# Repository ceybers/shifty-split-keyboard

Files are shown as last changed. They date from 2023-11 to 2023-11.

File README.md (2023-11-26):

# Shifty Split Keyboard

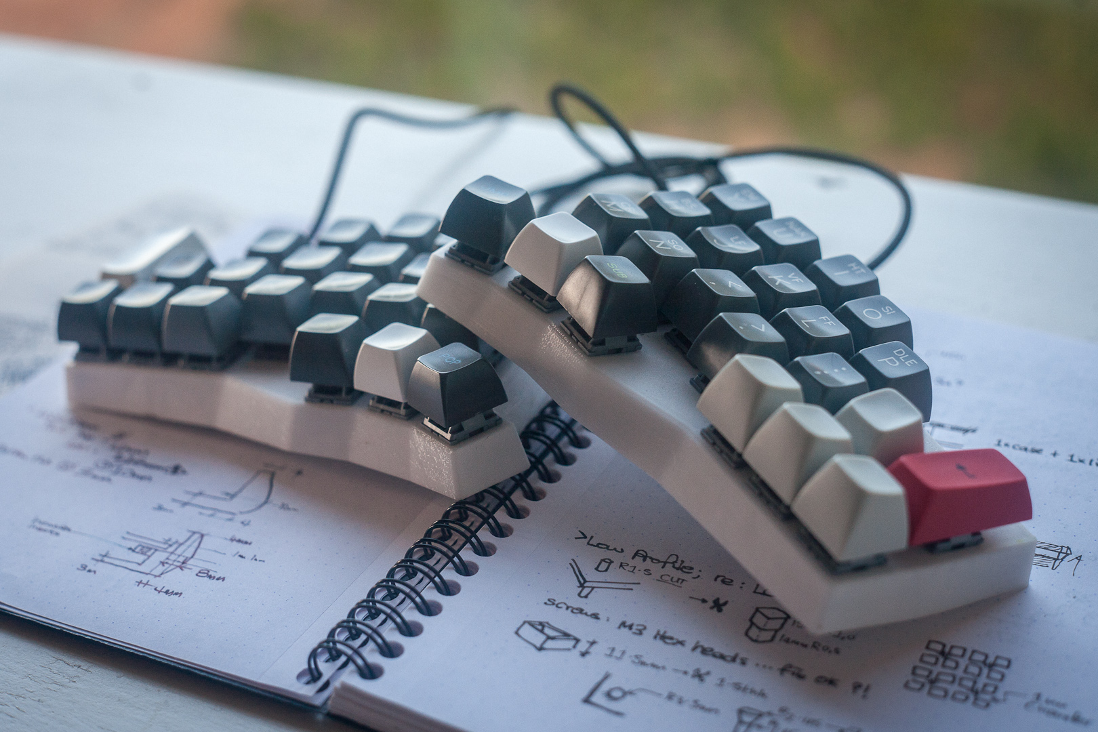
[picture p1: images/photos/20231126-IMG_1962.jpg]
Photo of my Shifty Split keyboard


## 📻 Project Description

Yet another 44-key handwired split keyboard. 

I liked the [Void Ergo S](https://github.com/victorlucachi/void_ergo), but I want to try a Corne style keyboard with a (semi-)dedicated arrow cluster, like the [Frame-48](https://github.com/gregsqueeb/Frame-48). I also added a vertical 2u key on each end where the numpad Enter key would be on a full-size keyboard, because of muscle memory, partially inspired by the [Skean's](https://github.com/krikun98/Skean) outer keys.

[Continue reading...](notes/Design.md)

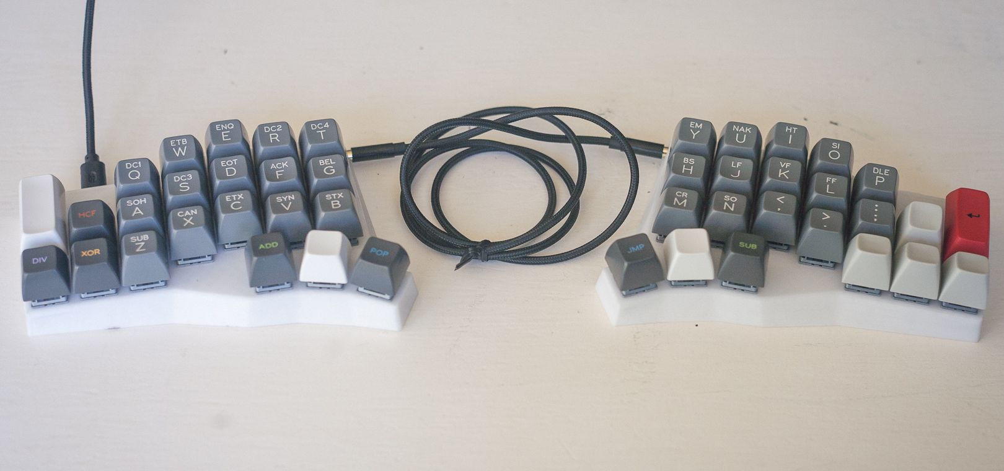
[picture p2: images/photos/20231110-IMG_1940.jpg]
Photo of my Shifty Split keyboard


## 🧰 Features
- 22×2 keys
- 2× RP2040 microcontrollers w/ USB-C on each side
- Split via TRS cable
- Powered by QMK with Vial support

## 📚 Read more...
- [Design](notes/Design.md)
- [Construction](notes/Construction.md)
- [Firmware](notes/Firmware.md)
- [Gallery](notes/Gallery.md)

## 🙏 Inspired by...
- [VOID Ergo S by Victor Lucachi](https://github.com/victorlucachi/void_ergo)
- [Frame-48 by Greg Mathews](https://github.com/gregsqueeb/Frame-48)
- [Skean by Alexander Krikun](https://github.com/krikun98/Skean)
- [MicroDox by Stephen Onnenon](https://github.com/onnenon/microdox-case/)
- [Unicorne by Boardsource](https://new.boardsource.xyz/products/unicorne)

## 📐 References
- [RP2040-Zero by Waveshare](https://www.waveshare.com/rp2040-zero.htm)
- [QMK Firmware](https://docs.qmk.fm/)
- [Vial Firmware](https://get.vial.today/)

---

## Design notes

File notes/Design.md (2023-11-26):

# Design
Yet another 44-key handwired split keyboard. 

I liked the [Void Ergo S](https://github.com/victorlucachi/void_ergo), but I want to try a Corne style keyboard with a (semi-)dedicated arrow cluster, like the [Frame-48](https://github.com/gregsqueeb/Frame-48). I also added a vertical 2u key on each end where the numpad Enter key would be on a full-size keyboard, because of muscle memory, partially inspired by the [Skean's](https://github.com/krikun98/Skean) outer keys.

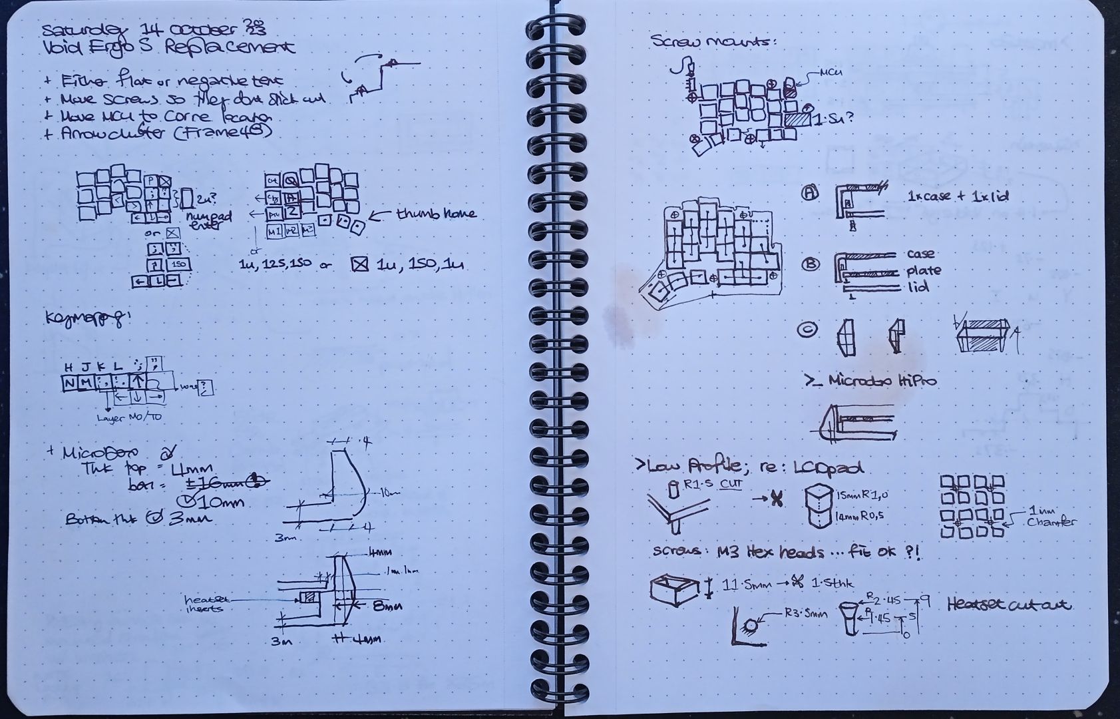
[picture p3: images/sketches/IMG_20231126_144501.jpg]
Sketch experimenting with arrow cluster


The arrow clusters line up nicely with the 5th and 6th column from the Void Ergo (same Y offset), and this conveniently leaves an empty key where the top row 6th column key would normally be, which is just enough space to fit a small RP2040 MCU. 

For the outer easy key, I chose a vertical 2u key because of years of muscle memory hitting the number pad Enter key. I was considering placing it horizontally, but I wasn't happy with the resulting silhouette of the keyboard, so I stuck to the current layout.

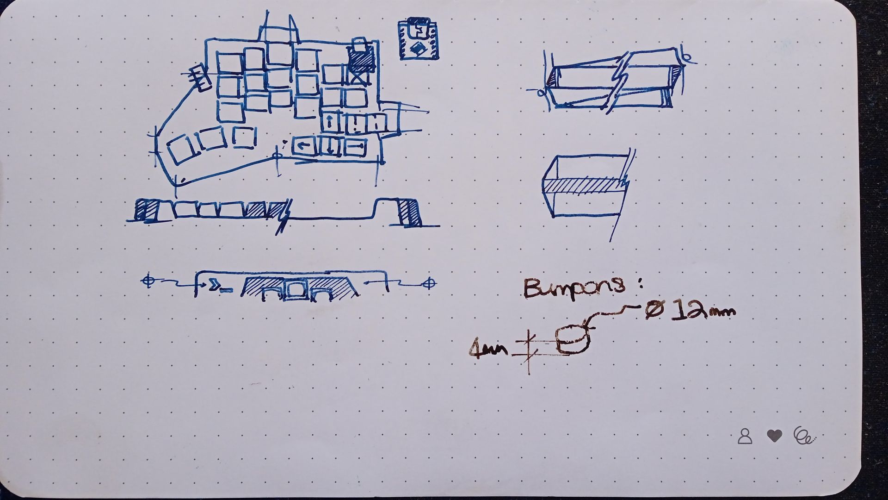
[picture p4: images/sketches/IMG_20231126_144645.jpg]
Sketch with horizontal outer key


It's 3D printed and handwired. The plate and the case are one part to avoid having to hassle with heatsets and screws. The bottom plate is recessed inside the walls of the top case, to hide imperfections with clearance and tolerance between the two parts. Then, I added a generous amount of slope and loft to the walls of the case to break up the silhouette because that appeals my personal taste.

As for the name? I needed something to put where the empty key was, so I decided to add a `>_>` face.

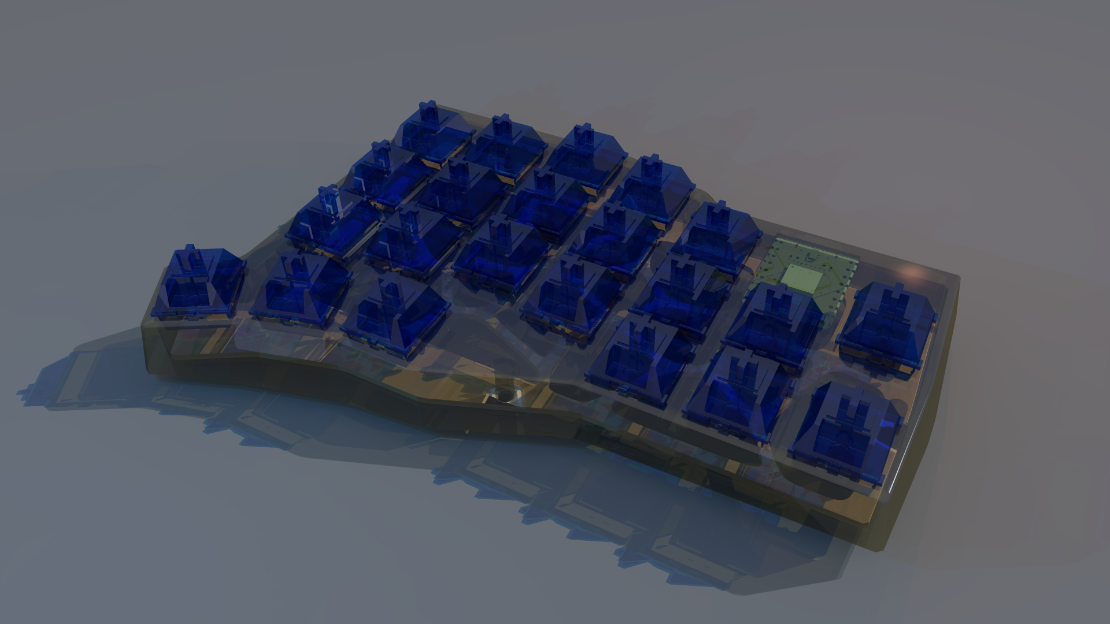
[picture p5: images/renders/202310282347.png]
Render of the Shifty Split keyboard


---

Next: [Construction](Construction.md) | Back to [README.md](../README.md)

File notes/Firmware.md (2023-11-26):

# Firmware
## QMK and Vial
For the firmware I first used the official [QMK](https://docs.qmk.fm/) repo to ensure everything is working and wired up correctly. Once I had the QMK firmware working and flashed to the board, I installed the [Vial](https://get.vial.today/) fork of QMK, and created a Vial-compatible firmware using their instructions.

I managed to get the WS2812 LED on the RP2040-Zero sort of working, but I could only change it inside the Vial interface and not using the actual keys, so I disabled it. Plus the LED faces down so the glow is rather faint. 

Still, it's useful while experimenting to indicate whether the keyboard has been flashed correctly.

## Keymaps
My keymaps were heavily inspired by manna-harbour's [Miryoku](https://github.com/manna-harbour/miryoku) layout, as well as learnings from Precondition's [Guide to Home Row Mods](https://precondition.github.io/home-row-mods).

### Layer 0
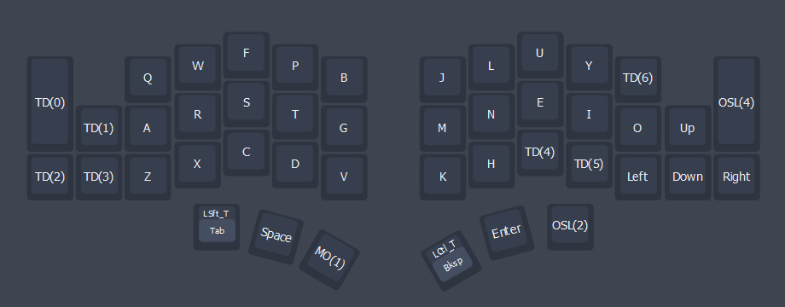
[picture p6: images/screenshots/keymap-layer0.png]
Keymap Layer 0

### Layer 1
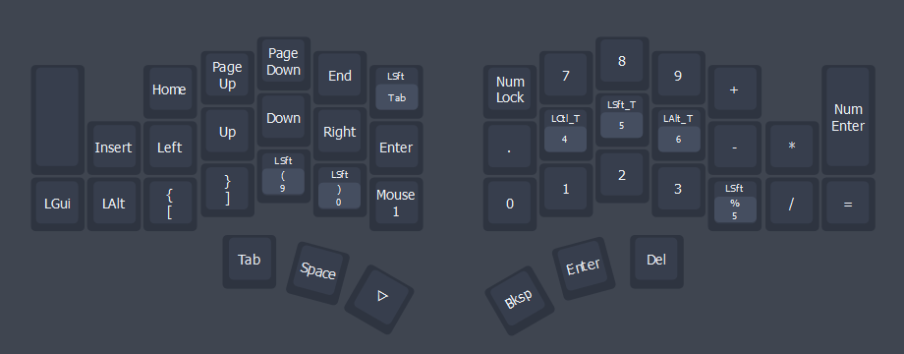
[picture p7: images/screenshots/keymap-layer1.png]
Keymap Layer 1

### Layer 2
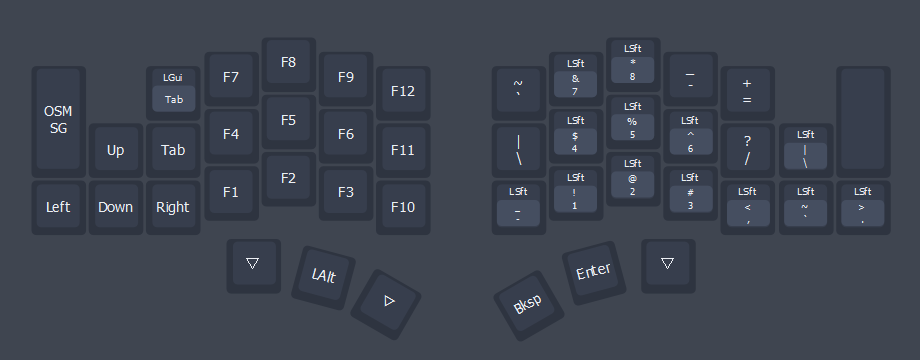
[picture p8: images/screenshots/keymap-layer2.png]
Keymap Layer 2

### Layer 4
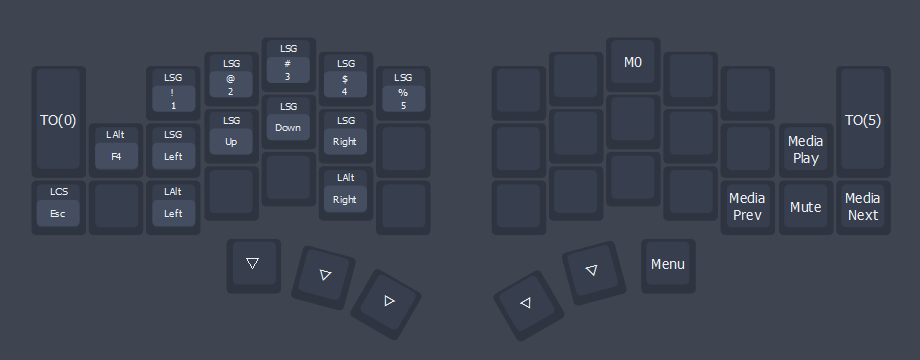
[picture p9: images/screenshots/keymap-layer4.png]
Keymap Layer 4

### Layer 5
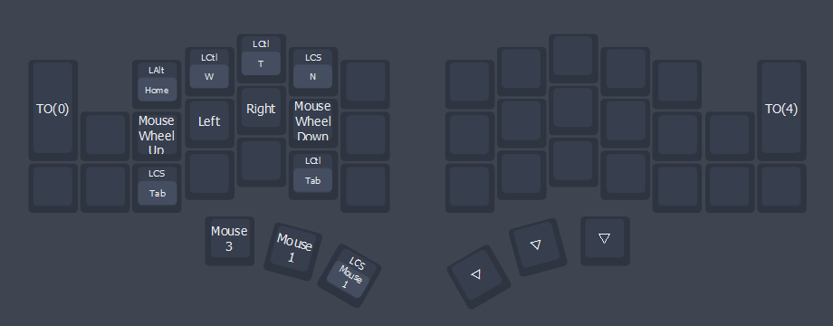
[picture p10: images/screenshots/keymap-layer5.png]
Keymap Layer 5


The tap dances on the left half are mostly hotkeys such as Ctrl-C, Ctrl-X, Ctrl-V, Ctrl-A, and Ctrl-C. I have tap dances for the command and period keys because I like having question mark, exclamation mark, single quote and quotation marks there.

I'm happy with my numpad layout and the navigation, but I'm not too sold on the brackets. Layer 2's symbols on the numpad are okay, but the ones around it don't feel very intuitive.

Layer 4 is handy because I have media keys by hitting the 2u key once (one-shot) then one of the arrow keys.

Hitting the 2u RHS key twice takes you to a browser layer, where the usual browser hotkeys are all a single tap, with mouse buttons available for making using a trackball with the right hand a bit easier.

## Some extra sketches
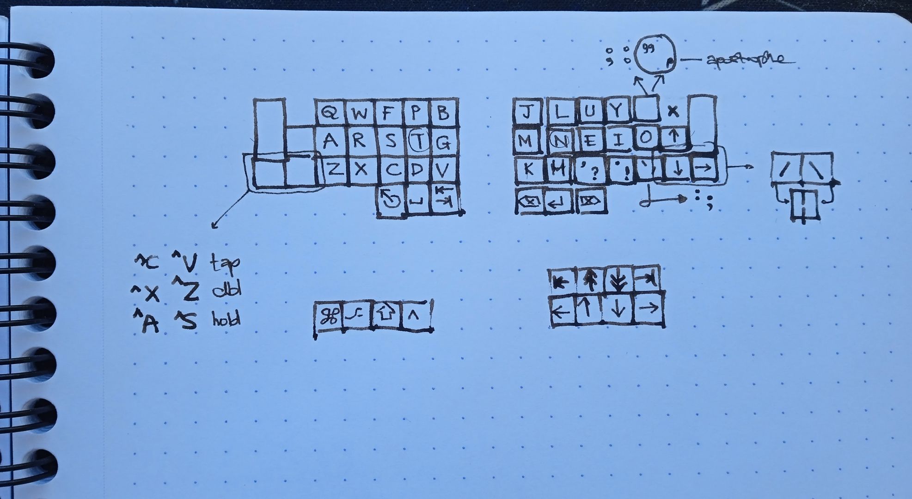
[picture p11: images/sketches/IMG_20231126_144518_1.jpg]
Sketch of preliminary base layer

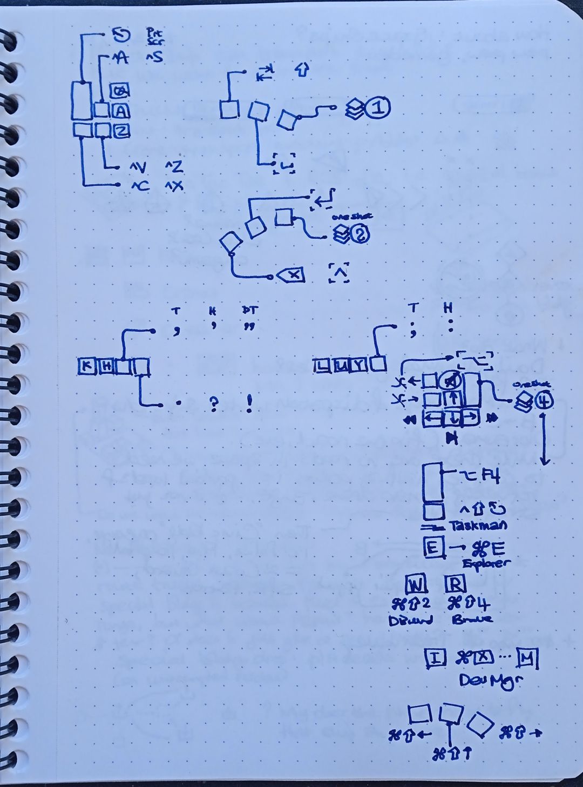
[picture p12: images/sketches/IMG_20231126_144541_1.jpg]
Sketches of some tapdance ideas

---

Back: [Construction](Construction.md) | Next: [Gallery](Gallery.md) | Back to [README.md](../README.md)

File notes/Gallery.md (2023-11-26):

# Gallery
## Photos
Artsy photo
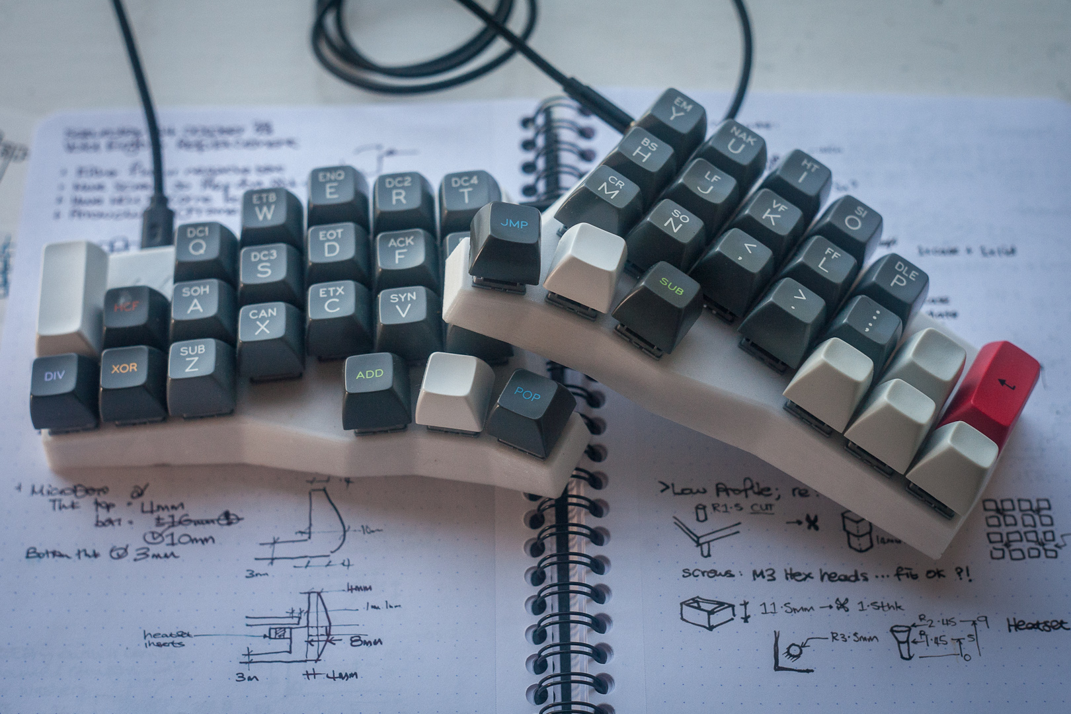
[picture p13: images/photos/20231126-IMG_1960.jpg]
Top down view

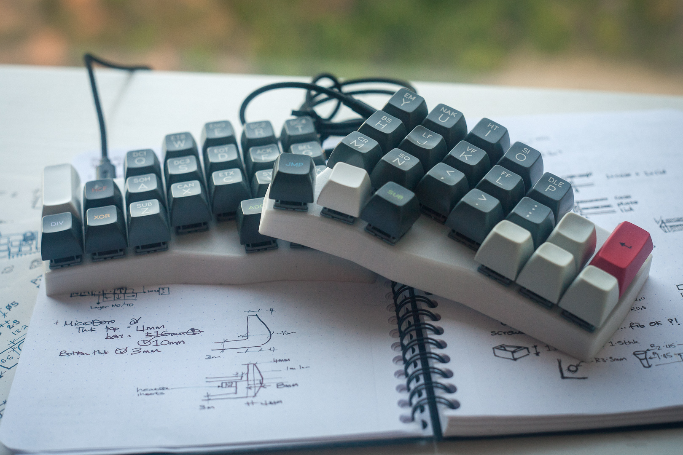
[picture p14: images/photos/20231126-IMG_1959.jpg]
Front angle view

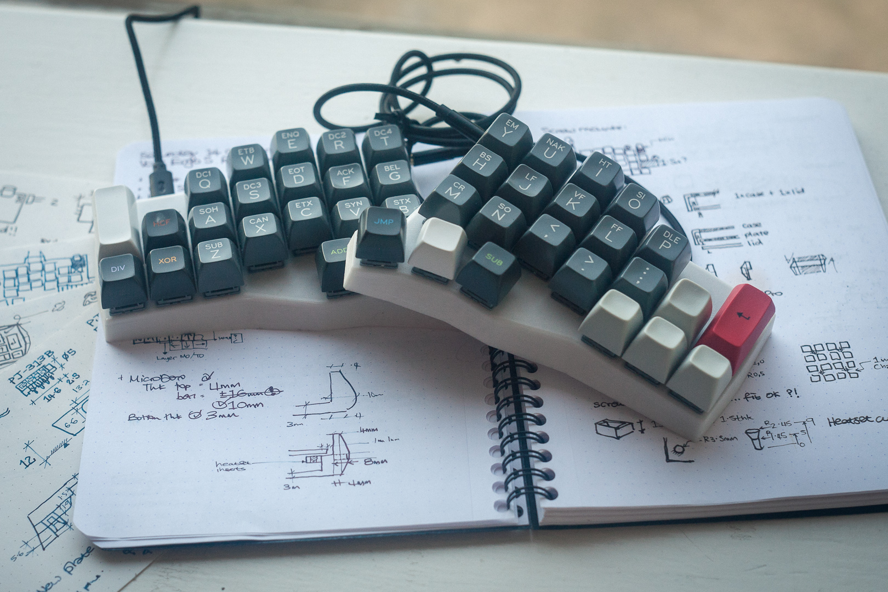
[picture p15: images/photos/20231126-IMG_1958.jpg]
Another top down view

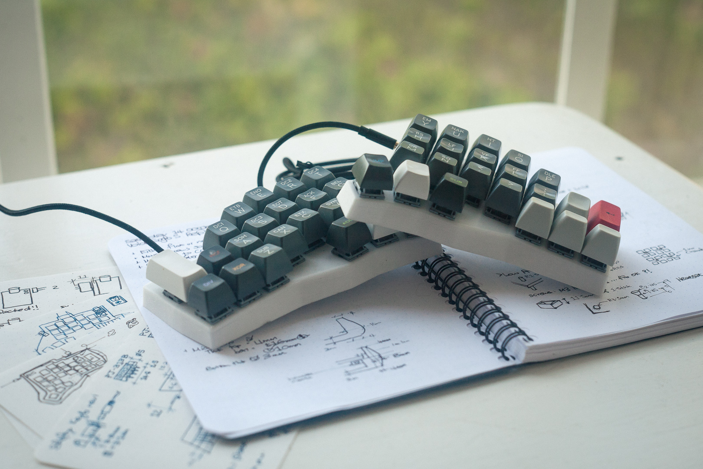
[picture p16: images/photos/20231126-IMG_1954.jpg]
Artsy angle view

Both halves
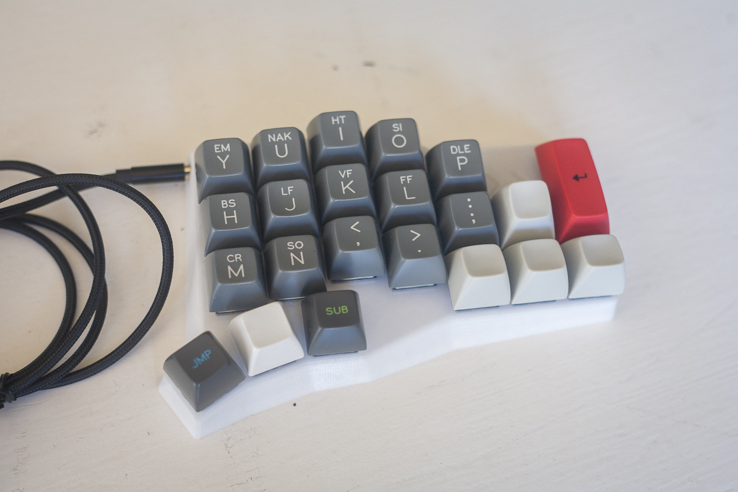
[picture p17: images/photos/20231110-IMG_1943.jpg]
Left half

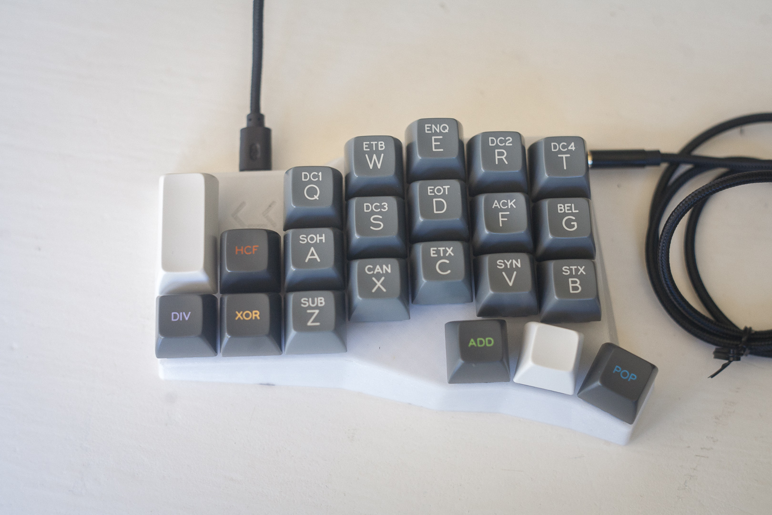
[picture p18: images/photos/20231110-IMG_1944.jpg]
Right half

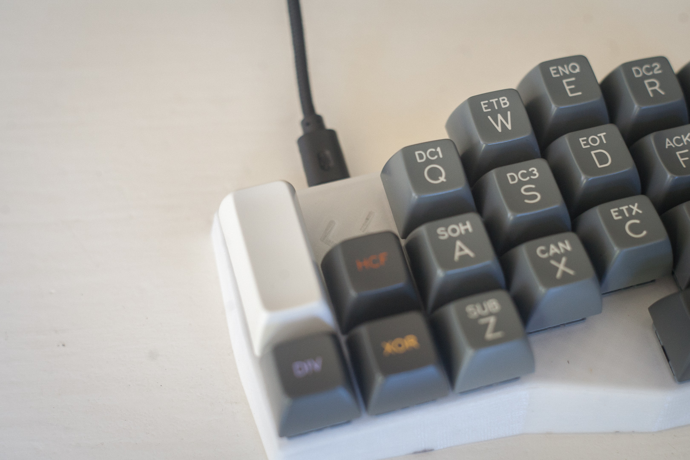
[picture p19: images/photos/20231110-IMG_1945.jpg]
Right half closeup

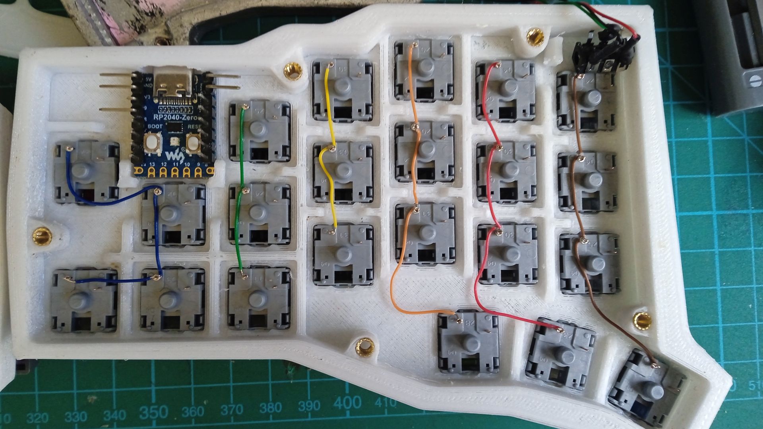
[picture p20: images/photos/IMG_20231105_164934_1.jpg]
Underside wiring


## Renders
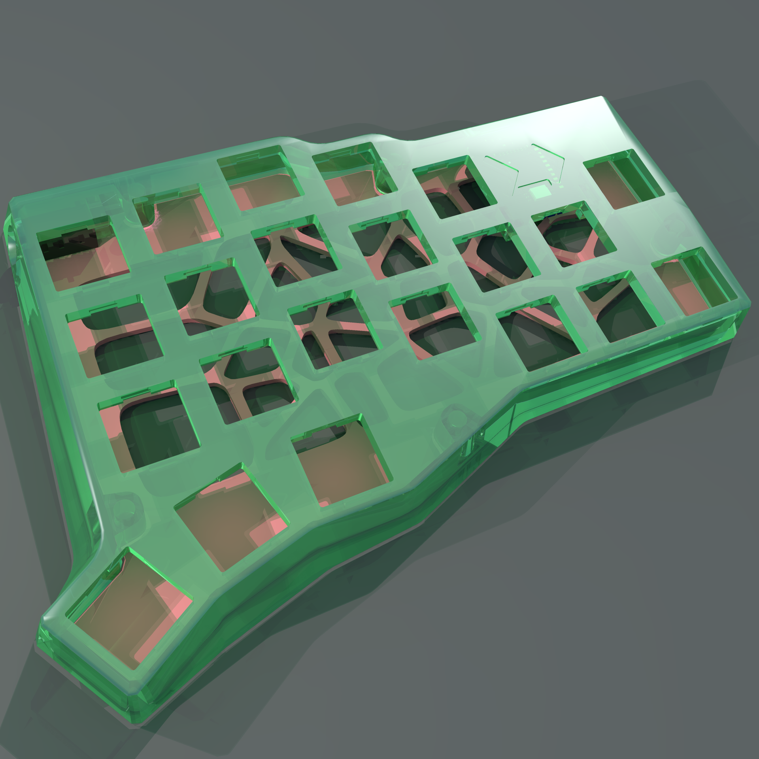
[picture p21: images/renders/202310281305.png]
Render w/o keys

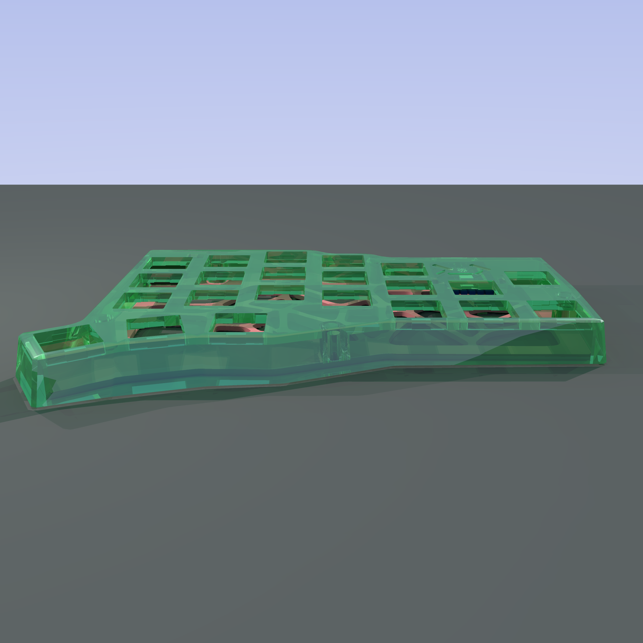
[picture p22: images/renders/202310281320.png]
Render w/o keys

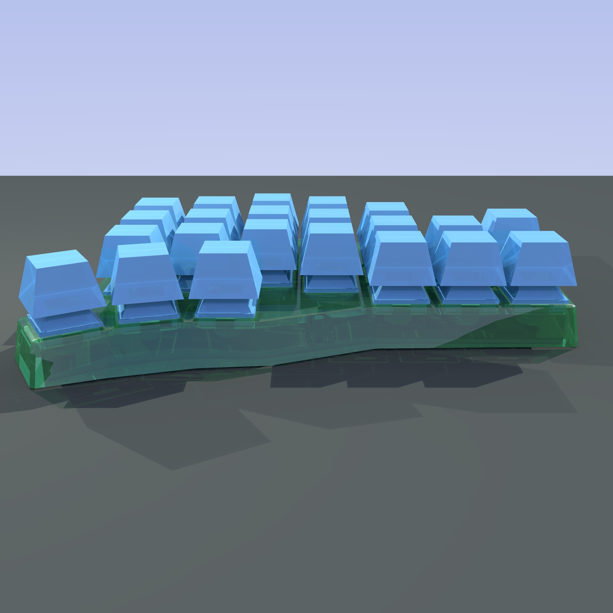
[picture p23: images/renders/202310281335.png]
Render w/ keys

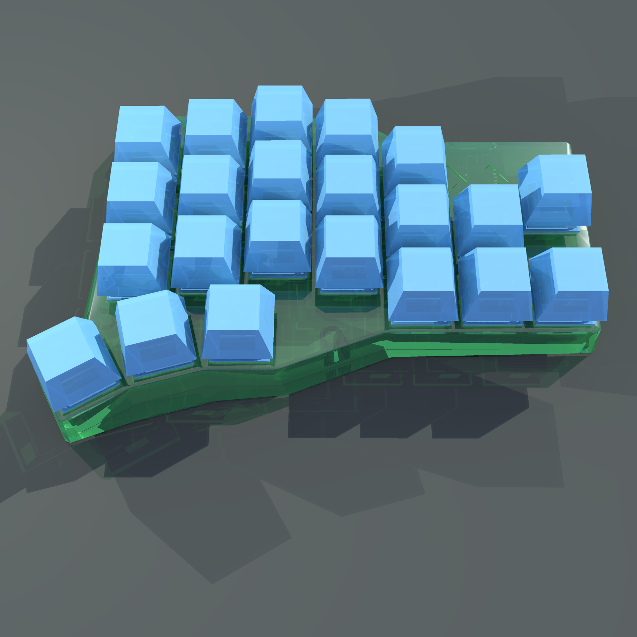
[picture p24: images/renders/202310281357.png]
Render w/ keys

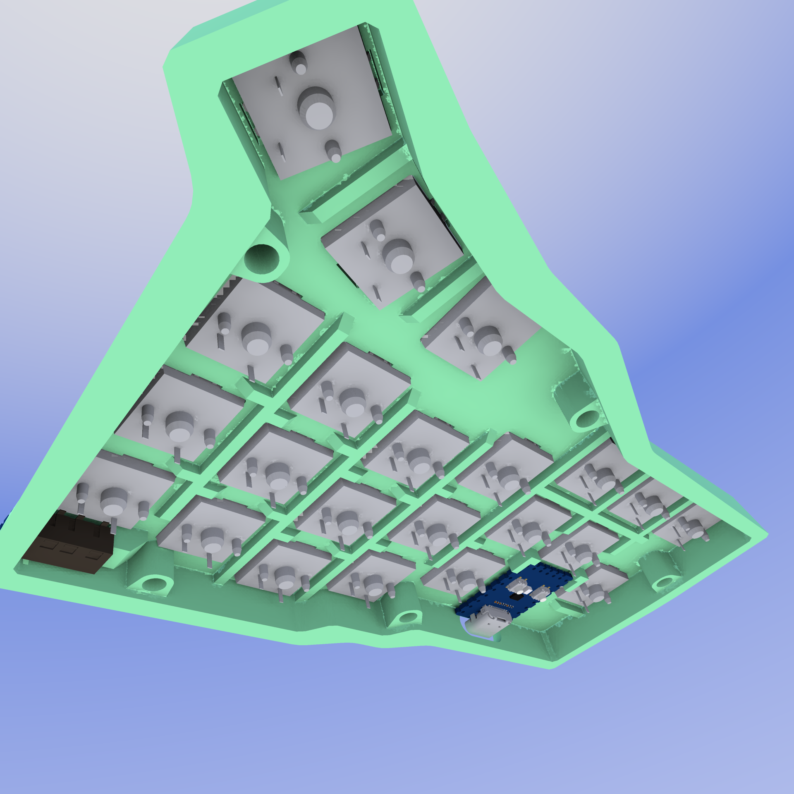
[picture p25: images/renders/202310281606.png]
Render underside

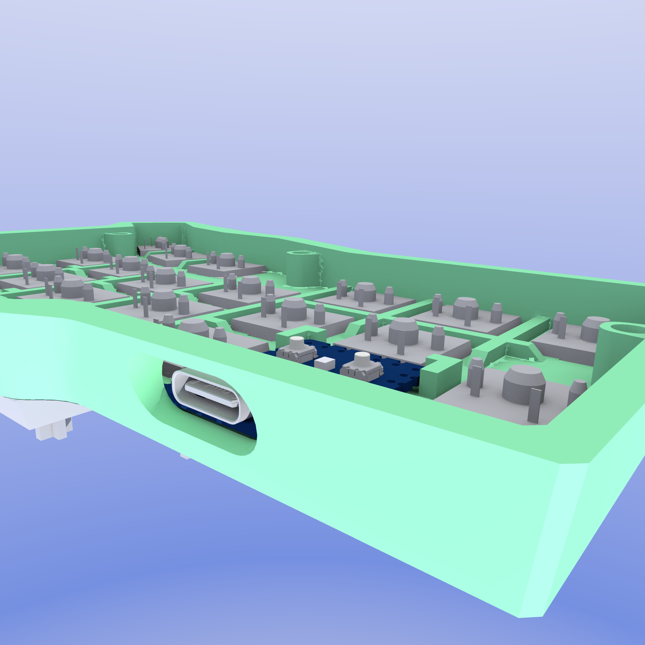
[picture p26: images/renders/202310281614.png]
Render underside USB-C

Upside down with bottom cover
Top transparent render

---

Back: [Firmware](Firmware.md) | Back to [README.md](../README.md)

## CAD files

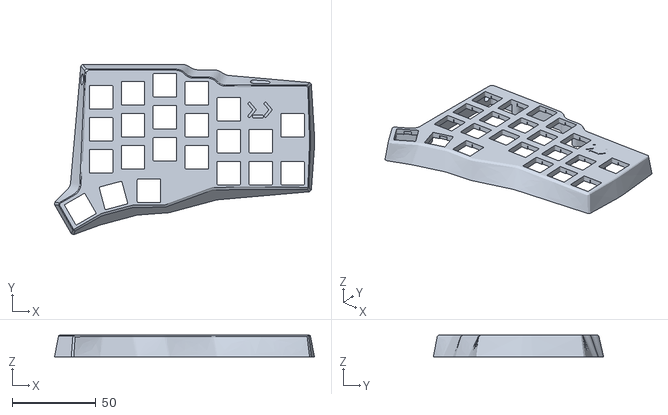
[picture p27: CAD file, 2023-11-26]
export/keyb-case-right-rev1.stl
155.1 x 101.6 x 13.0

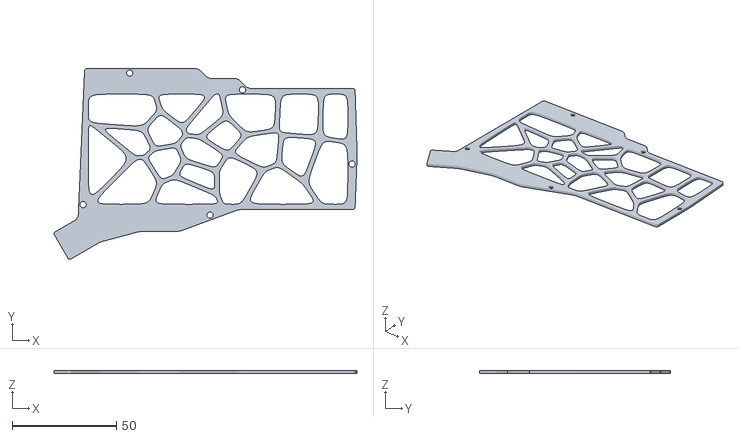
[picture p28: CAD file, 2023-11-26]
export/keyb-bottom-right-rev0.stl
145.1 x 91.3 x 1.50

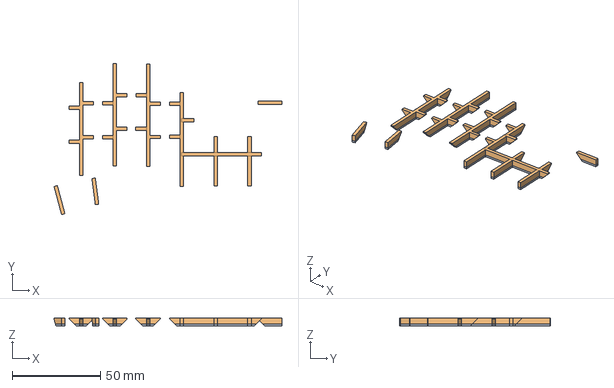
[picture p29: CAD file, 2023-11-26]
freecad/CaseRibbing.FCStd
129.1 x 85.6 x 4.50 mm
CaseRibNice

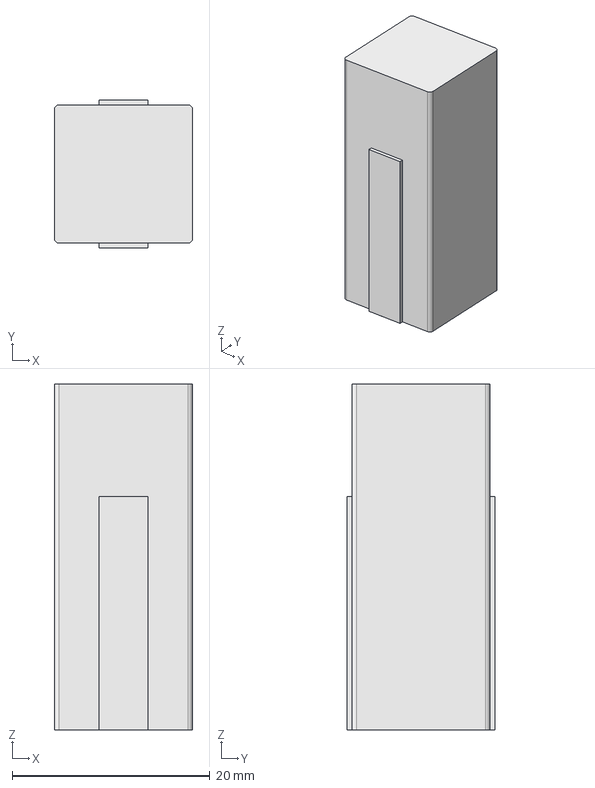
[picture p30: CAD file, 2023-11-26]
freecad/MXCutout.FCStd
14.0 x 15.0 x 35.0 mm

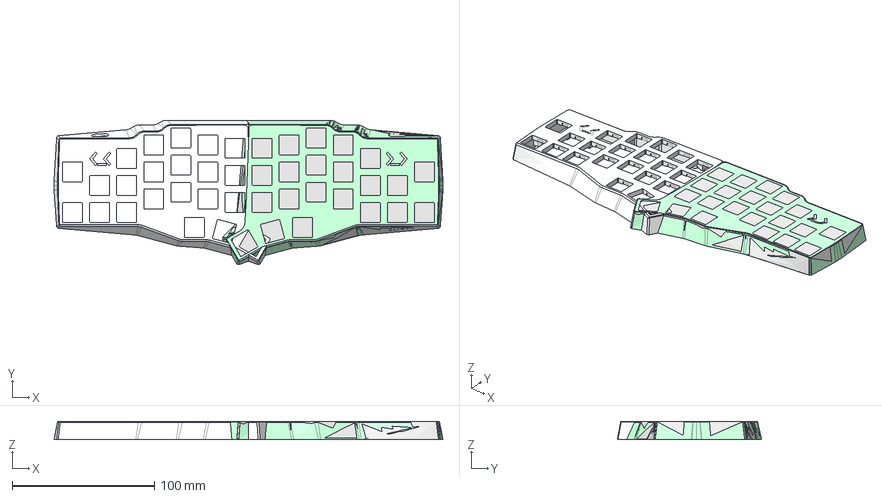
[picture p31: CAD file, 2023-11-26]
freecad/plate6.FCStd
273.7 x 101.6 x 13.0 mm
CaseSolid
CaseNice
CaseNice (Mirror #1)

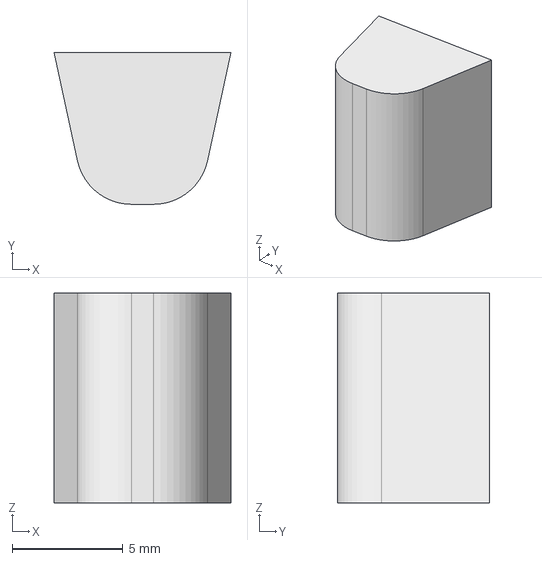
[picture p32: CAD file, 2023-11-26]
freecad/HeatSetInsertHolder.FCStd
8.00 x 6.86 x 9.50 mm

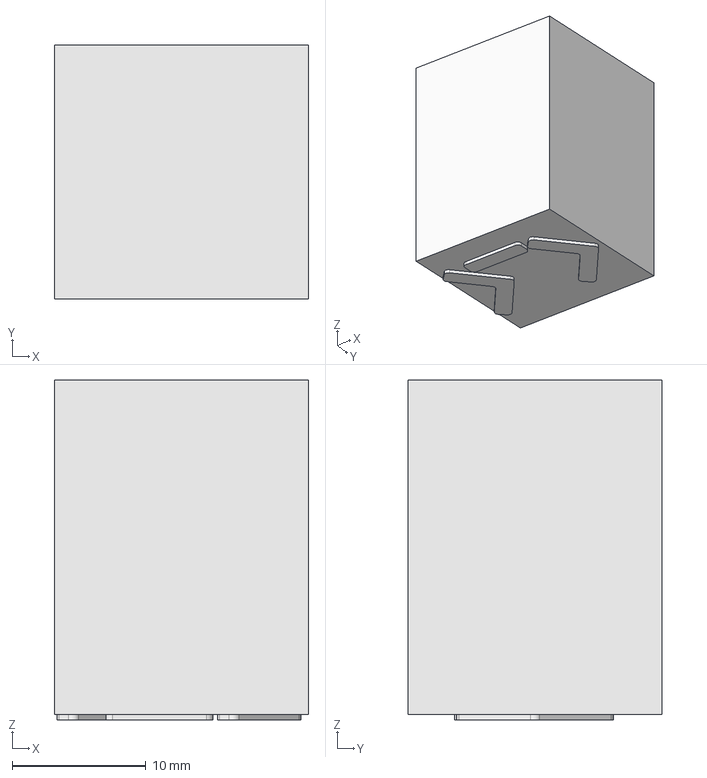
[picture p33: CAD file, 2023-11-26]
freecad/Shifty.FCStd
19.0 x 19.0 x 25.4 mm

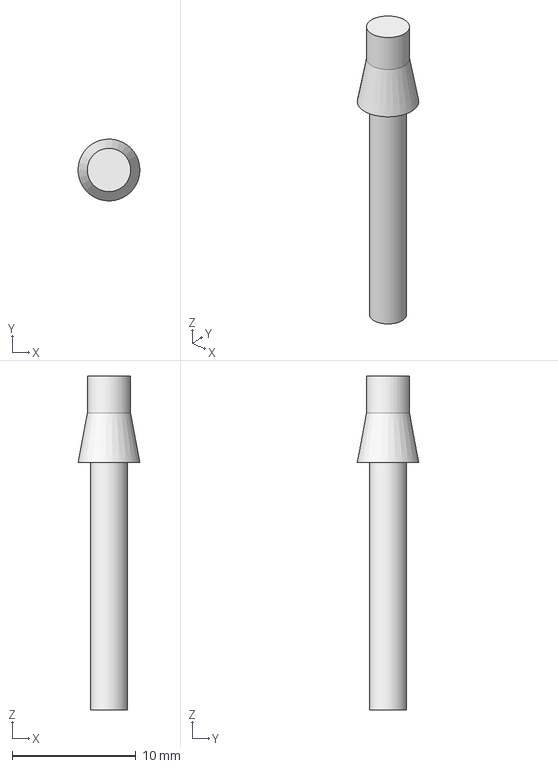
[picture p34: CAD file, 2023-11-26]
freecad/ScrewAndInsertCutout.FCStd
5.00 x 5.00 x 27.0 mm

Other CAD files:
export/keyb-case-left-rev1.stl
freecad/CombinedScene.FCStd
export/keyb-bottom-left-rev0.stl

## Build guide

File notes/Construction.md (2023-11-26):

# Construction

## 🛒 Bill of Materials (BOM)

| Item | Size | Qty | 
| ---- | ---- | --- |
| [Waveshare RP2040-Zero](https://www.waveshare.com/rp2040-zero.htm) | N/A | 2 |
| Switches | MX | 44 |
| Diodes, 1N4148 | 1N4148 | 44 |
| PJ320D 3.5mm Female | TRS† | 2|
| Heat Set Inserts | M3 ø4x5mm | 10 |
| Screws, countersunk | M3 | 10 |
| Wire | 30AWG | N/A |
| 3D printed shell | N/A | 4 pcs |

† Test the cable(s) you intend using, as TRS and TRRS connectors are not always compatible.

## 📸 Photos
I didn't take many photos during the build of this one. The biggest challenge is the tight spacing around the MCU, as can be seen below:

Photo from beneath showing column wiring

Note the 90 degree header pins next to the USB-C port. These are for 3v3, GND, and a serial pin for the split cable between the halves. For this I decided to use a battery header pins because they're sturdier than the usual 30AWG wire I use that *does* tend to come loose on occasion.

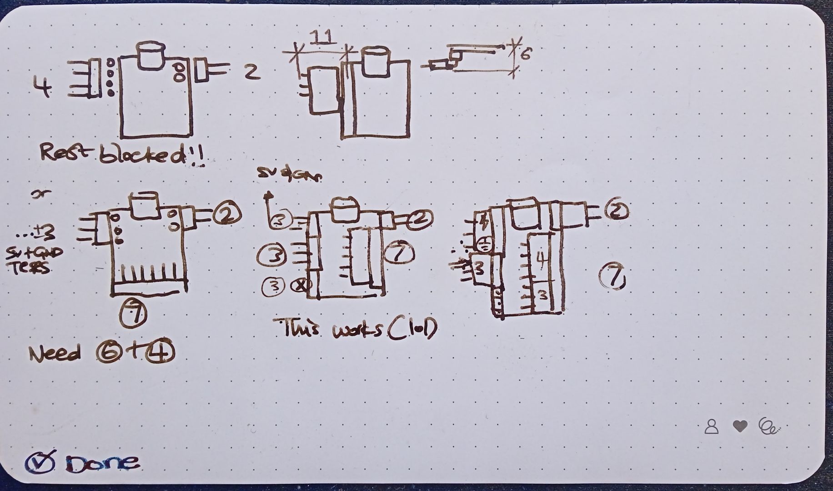
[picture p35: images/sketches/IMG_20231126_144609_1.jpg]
Sketches of MCU pin placement


For the switches, the balance of the pins are vertical pins. I revised the height of the case so that the height of the case is barely just enough to contain them, althought the ends might need to be trimmed with wire cutters.

For this build I greatly recommend using a wire wrapping tool, it was a complete life changer. 

My previous method was to attach female headers on to the MCU's pins, manually wrap 30AWG wire around each pin, solder it, then cover it in insulation tape. 

Using a wire wrapping tool is much less bulky than a pair of male and female header sockets, and they can be removed without needing to desolder. So far the connection has been sturdy enough for every day use, though bear in mind I leave this keyboard at home and don't travel with it.

After the first print I refined some dimensions, mostly the USB-C and TRS cutouts on the case.

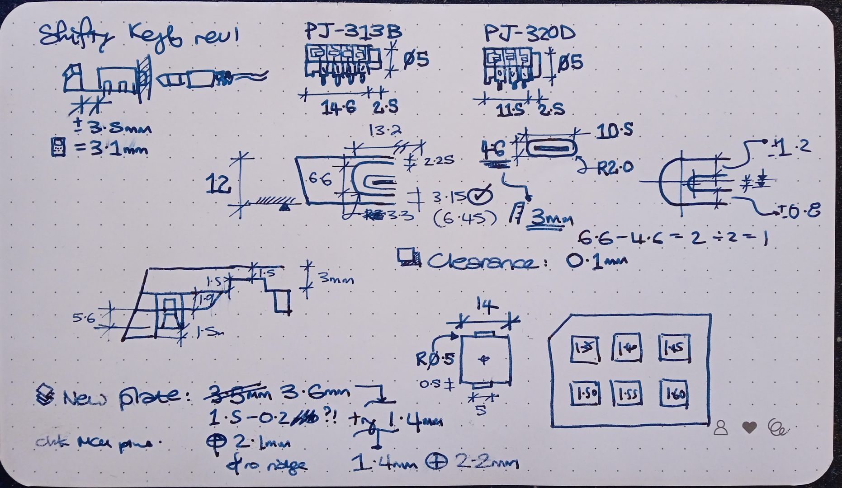
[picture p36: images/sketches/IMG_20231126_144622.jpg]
Sketches of dimension adjustments


---
Back: [Design](Design.md) | Next: [Firmware](Firmware.md) | Back to [README.md](../README.md)
